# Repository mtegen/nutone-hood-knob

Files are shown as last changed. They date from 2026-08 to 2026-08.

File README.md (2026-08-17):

# NuTone range-hood control knob — 3D-printed replacement

A replacement for the broken control knob on a NuTone kitchen range hood (the "exhaust
ON·OFF·LOW / SOLID STATE" panel). The original is a sixty-ish-year-old moulded knob whose
socket had split.

**Status: printed and working.** ✅ The part as modelled here fits the hood's shaft and drives
the switch. See [What the print confirmed](#what-the-print-confirmed).

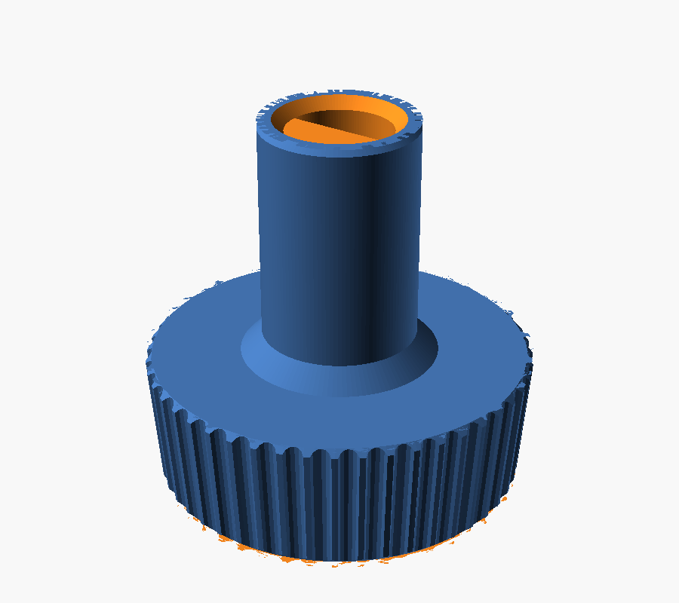
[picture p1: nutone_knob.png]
the knob


## The part

```
        <-------- 27.35 back -------->      the dial you turn, knurled,
         ___________________________        tapering to 25.80 at the front
        |                           |       9.50 tall
        |___________________________|
                |         |                 <- stem 11.00, parallel
                |         |                    17.00 long
                |  Ø7.00  |                    2.00 of wall around the bore
                |  D bore |
                |_________|

                overall 26.50 = 9.50 + 17.00
```

**The overall height is derived, never entered** — it is dial + stem and nothing else, so the
two heights cannot disagree with a third number.

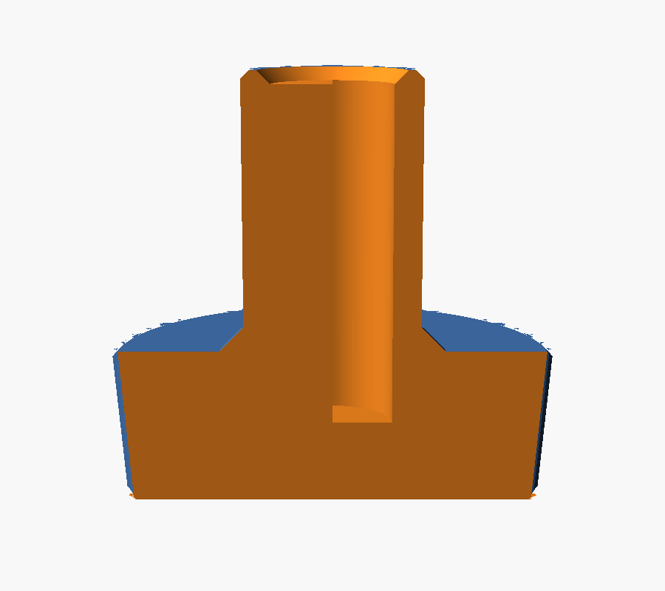
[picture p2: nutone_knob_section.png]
section


## Files

| | |
|---|---|
| `nutone_knob.scad` | the model — every dimension is one variable at the top |
| `nutone_knob.stl` | the knob, ready to print |
| `nutone_knob_gauge.stl` | fit gauge, six stations, ~2 min print |
| `check_stl.py` | is the mesh one solid, closed, and grounded? |
| `measure_stl.py` | is it the right size? measures the STL, not the model's arithmetic |
| `clean_stl.py` | drops zero-area facets from the export |

## Printing

- **Orientation: front face DOWN on the plate, stem pointing up.** The bore then prints as a
  clean vertical blind hole needing no support, and elephant foot lands on the dial's front
  rim where the 0.60 chamfer absorbs it, not on a fit surface. Stem-down would put the splay
  right at the bore mouth — the one place it must not be — and need support under the dial.
- **No supports needed anywhere.** The dial's taper is 2.6° off vertical and the gusset is a
  45° cone; both are self-supporting.
- 0.16 mm layers, **4 walls**, 30–40 % infill.
- ⚠ **Walls, not infill, resist the twist.** Torque tries to shear the stem along the layer
  lines, which is FDM's weak direction — hence four perimeters. The 1.5 mm gusset at the
  stem/dial junction is there for the same reason: that corner is where the original broke.

### Material

PLA prints this fine and is the most dimensionally predictable choice. The reservation is
that this is a **range hood** — PLA softens around 60 °C and creeps under sustained load, and
a knob pressed onto a shaft is under constant load. PETG (~80 °C) or ASA (~100 °C) have real
margin. If the panel on your hood runs warm, use one of those for the keeper.

## Print the gauge first

Two minutes, against a shaft you would otherwise be guessing at.

```bash
openscad -D 'part="gauge"' -o nutone_knob_gauge.stl nutone_knob.scad
```

Six stations: five D sockets stepping the bore, one plain round hole as a control.

- **A D station grips firmly and square** → that is your number. Set `socket_fit` so `bore_d`
  matches it, re-export, print the knob.
- **No D station goes on but the round control does** → the bore is fine and the **flat** is
  wrong. Measure flat face → opposite arc and raise `shaft_flat`.
- **Nothing goes on at all** → `shaft_d` is under. Raise it.

| Station | Modelled bore | Prints about |
|---|---|---|
| `14` | 7.14 | 6.95 — tight |
| `24` | 7.24 | 7.05 |
| `34` | 7.34 | **7.15 — the knob's default** |
| `44` | 7.44 | 7.25 |
| `54` | 7.54 | 7.35 — loose |
| `RND` | 7.34 round, no flat | control |

## The measurements

All taken with calipers on the shaft and the old knob.

| | |
|---|---|
| `shaft_d` 7.00 | across the shaft's round part at its widest, measured on the **shaft** — a cracked socket splays and reads oversize |
| `stem_d` 11.00 | parallel, does not taper |
| `stem_l` 17.00 | how far the stem stands off the back of the dial |
| `grip_d_back` 27.35 | widest, against the panel |
| `grip_d_front` 25.80 | the face you look at |
| `grip_t` 9.50 | the dial's own height |

⚠ **Do not scale these off photographs.** An earlier revision derived the dial from the
photos and got 22.7 against a real 27.35 — 20 % out. Photographs settle the *shape* on this
job; they have no business setting a *size*. Where a caliper reading and a pixel ratio
disagreed here, the pixels were wrong every time.

## Printer compensation

Built on a Bambu A1 mini's **measured** behaviour, not published ranges. Three effects, all
compensated in the model so the STL is correct whoever slices it:

| Effect | Value | Applied as |
|---|---|---|
| Holes print under | `hole_shrink` 0.19 | bore drawn **over**: `7.00 + 0.19 + 0.15 fit = 7.34` |
| Outsides print over | `ext_grow` 0.15 | every outer dia drawn **under**: 25.80 → 25.65 |
| Elephant foot | `foot_chamfer` 0.60 | chamfer on the front face, which sits on the plate |

0.19 is interpolated for Ø7 between measured 0.20 at Ø6 and 0.15 at Ø10; shrinkage scales
with hole-to-nozzle ratio, so the small-hole figure does not carry across.

This is why the STL measures "wrong" in a viewer — 25.65 where you expect 25.80. It is drawn
small on purpose so it comes off the plate at size.

⚠ **If you enable X-Y hole/contour compensation or elephant-foot compensation in your slicer,
zero `hole_shrink`, `ext_grow` and `foot_chamfer` here** — otherwise it is applied twice and
the socket comes out ~0.19 too loose.

## What the print confirmed

The knob printed from `nutone_knob.stl` fits the shaft and drives the switch. That retires the
last open assumption:

- ✅ **`shaft_flat` = 3.50 — the shaft really is a true half-round**, flat through the centre.
  This was an inference from the words "a half circle" and was the single most likely thing
  to be wrong. The part going on proves it.
- ✅ **The bore at 7.34 modelled is right** — the 0.19 hole-shrink and 0.15 clearance together
  land where they should on a 7.00 shaft.
- ✅ **The compensation figures carry to this part**, at least in the material used for this
  print. (Material for the successful print is not recorded here — worth noting if you
  reprint in something else, since PETG and PLA do not shrink identically.)

## Verified dimensions

Measured back off the exported STL with `measure_stl.py`, not taken from the model:

| Feature | Modelled | Prints |
|---|---|---|
| Overall height | 26.50 | — |
| Dial, front | 25.65 | 25.80 |
| Dial, back (widest, z=9.04) | 27.13 | 27.28 |
| Stem (z 9.50 → 26.00) | 10.85 | 11.00 |
| Bore | 7.34, flat on centre | ~7.15 |
| Wall around bore | 1.76 | 1.93 |
| Front face | 5.00 solid | socket 21.50 deep |

## If it does not fit

Every fit is one variable at the top of the `.scad`. Change one, re-export, re-verify.

| Symptom | Change |
|---|---|
| Socket will not start on the shaft | raise `socket_fit` (0.15 → 0.25) |
| Socket goes on but the knob spins | lower `socket_fit`; if it still spins, `shaft_flat` is too big — the flat is not driving |
| No bore goes on, round control does | lower `shaft_flat` — the flat is cut deeper than half |
| Knob will not seat flush to the panel | raise socket depth: lower `front_wall` (5.00 → 3.00) |
| Knob stands too proud / too deep | change `grip_t` or `stem_l`; overall follows automatically |
| Stem splits while pressing on | raise `socket_fit`, print PETG, raise `fillet` |
| Knurl feels smooth | raise `flute_depth` (0.45 → 0.60) or lower `flutes` (48 → 36) |

## Verifying an export

```bash
openscad -D 'part="knob"' -o nutone_knob.stl nutone_knob.scad \
  && python3 clean_stl.py nutone_knob.stl \
  && ./check_stl.py nutone_knob.stl \
  && ./measure_stl.py nutone_knob.stl
```

`clean_stl.py` is needed because where a chamfer cone meets a flank the two surfaces are
tangent along a ring, and CGAL tessellates that into zero-area slivers (48 on the current
version). They enclose no volume but leave edges pairing with nothing, so `check_stl.py`
counts them as open. Dropping them took the count to **zero**, which is the proof there was
never a hole — a real hole would have survived the drop. **Always re-run `check_stl.py` after
cleaning**; the cleaner is not trusted on its own say-so.

## Not modelled

The white printed insert in the original's front face. `insert_recess = false` ships a flat
front — the insert's diameter was never measured, and printing front-face-down turns a recess
into a bridged ceiling. Options: reuse the original insert glued to the flat front, or set
`insert_recess = true` with a real `insert_d` and accept the bridge.

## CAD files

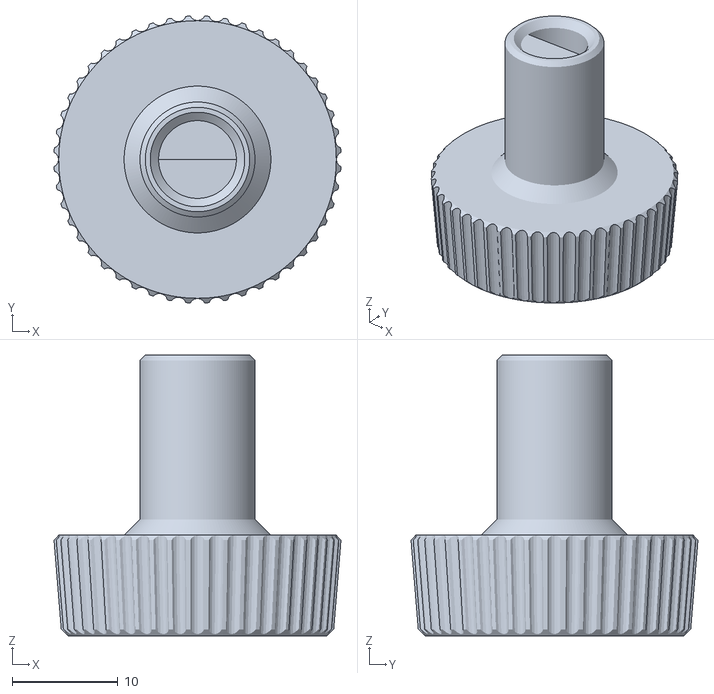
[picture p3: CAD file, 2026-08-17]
nutone_knob.stl
27.1 x 27.1 x 26.5

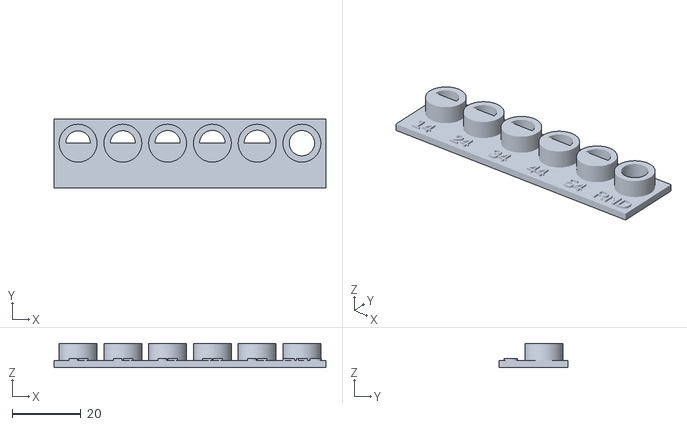
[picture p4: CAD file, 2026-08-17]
nutone_knob_gauge.stl
79.0 x 20.0 x 7.00

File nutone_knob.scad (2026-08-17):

// NuTone range-hood control knob — replacement
//
// Standalone. Nothing here is shared with any other project.
//
// ⚠ THE SHAPE IS STEPPED. A NARROW STEM carries the D socket; behind it a MUCH WIDER KNURLED
// GRIP is the part a person touches. An early version modelled the whole thing as one 10.8
// tube. That was wrong and the owner caught it.
//
// ⚠ SIZES ARE MEASURED, NOT SCALED OFF PHOTOGRAPHS. An earlier version derived the grip from
// the photos and got 22.7 against a real 27.35 — 20% out. Photographs settle the SHAPE here;
// they have no business setting a SIZE.
//
// ⚠ THE OVERALL HEIGHT IS DERIVED, NOT ENTERED. It is grip_t + stem_l and nothing else, so
// the two heights can never disagree with a third number. Asking for an overall reading when
// both pieces were already given was my mistake, not a missing measurement.
//
//        <-------- grip_d 27.35 back -------->    the part you touch, knurled,
//         ___________________________________     tapering to 25.80 at the front
//        |                                   |    grip_t 9.50
//        |___________________________________|
//                    |         |                  <- stem_d 11.00, parallel
//                    |         |                     stem_l 17.00
//                    |  O7.00  |                     2.00 of wall around the bore
//                    |  D bore |
//                    |         |
//                    |_________|
//
//                    overall 26.50 = 9.50 + 17.00
//
// Exports:
//   openscad -D 'part="knob"'  -o nutone_knob.stl       nutone_knob.scad
//   openscad -D 'part="gauge"' -o nutone_knob_gauge.stl nutone_knob.scad

part = "knob";              // "knob" | "gauge" | "section"

/* ---- MEASURED by the owner, with calipers ------------------------------------------ */
shaft_d      = 7.00;       // MEASURED on the hood's shaft itself, across the round part at
                           // its widest. Measured on the SHAFT, not the broken socket — a
                           // cracked socket splays open and reads oversize.
stem_d       = 11.00;      // MEASURED. Parallel — it does NOT taper.
stem_l       = 17.00;      // MEASURED, how far the stem stands off the back of the dial
grip_d_back  = 27.35;      // MEASURED, at the back — the widest end, against the panel
grip_d_front = 25.80;      // MEASURED, at the front — the face you look at
grip_t       =  9.50;      // MEASURED, the dial's own height

/* ---- STILL NOT MEASURED — each is one variable ------------------------------------- */
shaft_flat   = 3.50;       // ⚠ ASSUMED a TRUE half-round: the flat through the shaft's
                           // centre, which is what "a half circle" encodes. If the flat is
                           // cut shallower this number is bigger and the socket will not go
                           // on. Measure flat face -> opposite arc. The gauge's round
                           // control station exists to catch exactly this.
front_wall   = 5.00;       // ⚠ CHOSEN, not measured. Sets the socket depth, and the error is
                           // ONE-SIDED: a socket deeper than the shaft costs nothing — the
                           // shaft just does not reach the bottom and the D drives the knob
                           // the same — while a socket shallower than the shaft stops the
                           // knob seating flush to the panel. So this errs deep on purpose.

/* ---- WHAT THE PRINTER DOES TO THESE NUMBERS -----------------------------------------
   Bambu A1 mini, 0.4 nozzle. Not published ranges — what this printer was measured doing:
     HOLES SHRINK   0.20 at O6, 0.15 at O10. Scales with hole-to-nozzle ratio, so O7 is
                    interpolated rather than taking the small-hole figure.
     OUTSIDES GROW  0.15.
     ELEPHANT FOOT  first layers splay; the front chamfer is sized for it, not decorative.
   ⚠ If you switch these on in Bambu Studio instead, zero them here or they apply twice. */
hole_shrink  = 0.19;
ext_grow     = 0.15;
foot_chamfer = 0.60;
edge_chamfer = 0.50;

socket_fit   = 0.15;       // diametral clearance, socket over shaft — a light press. The
                           // knob is held on by friction; the original has no set screw.

/* ---- APPEARANCE ---------------------------------------------------------------------- */
flutes       = 48;         // knurl count on the GRIP. 48 around 27.35 is a 1.79 mm pitch,
                           // which a 0.4 nozzle can actually render. Finer just blobs.
flute_depth  = 0.45;
fillet       = 1.50;       // gusset where the stem meets the grip. Not cosmetic — this is
                           // the junction that carries all the torque, and the original
                           // broke at the stem.
insert_recess= false;      // the original's white printed disc; see NUTONE-KNOB.md
insert_d     = 21.00;
insert_deep  = 0.80;

$fn = 128;

/* ==== DERIVED ========================================================================= */
total_h   = grip_t + stem_l;                 // 26.50 — the owner's two heights, added
socket_depth = total_h - front_wall;         // 21.50 — through the stem, into the grip

bore_d    = shaft_d + hole_shrink + socket_fit;
bore_r    = bore_d / 2;
bore_flat = shaft_flat + (hole_shrink + socket_fit) / 2;
flat_y    = bore_r - bore_flat;              // 0 when it is a true half-round

gd_front  = grip_d_front - ext_grow;
gd_back   = grip_d_back  - ext_grow;
sd        = stem_d       - ext_grow;

/* ==== PARTS =========================================================================== */

// The D socket, as a solid to subtract. Origin at its mouth, growing +z.
module d_socket(depth) {
    intersection() {
        cylinder(d = bore_d, h = depth);
        translate([-bore_d, flat_y, 0]) cube([2 * bore_d, 2 * bore_d, depth]);
    }
}

// Removes everything outside a 45-degree cone, giving a chamfer in a thin z band.
// grow=true chamfers a bottom edge, false chamfers a top edge.
module chamfer_ring(z0, d, ch, grow = true) {
    translate([0, 0, z0]) difference() {
        cylinder(d = d + 10, h = ch);
        if (grow) cylinder(d1 = d - 2 * ch, d2 = d + 0.01, h = ch);
        else      cylinder(d1 = d + 0.01,   d2 = d - 2 * ch, h = ch);
    }
}

// The knurled grip, tapering front to back. Knurl on the grip only — the stem is smooth,
// as on the original.
// ⚠ The flute cutters get their OWN low segment count. Left on $fn=128 a 1.4 mm circle is
// tessellated far finer than the printer can resolve, and where those arcs cross the body's
// arc they produce zero-area sliver triangles.
module grip() {
    linear_extrude(height = grip_t, scale = gd_back / gd_front, convexity = 10)
        difference() {
            circle(d = gd_front);
            for (i = [0 : flutes - 1])
                rotate([0, 0, i * 360 / flutes])
                    translate([gd_front / 2 + 0.70 - flute_depth, 0])
                        circle(d = 1.40, $fn = 16);
        }
}

module knob() {
    difference() {
        union() {
            grip();
            translate([0, 0, grip_t]) cylinder(d = sd, h = stem_l);          // the stem
            translate([0, 0, grip_t])                                        // the gusset
                cylinder(d1 = sd + 2 * fillet, d2 = sd, h = fillet);
        }

        // The socket, opening at the stem tip and reaching down into the grip.
        translate([0, 0, total_h - socket_depth]) d_socket(socket_depth + 0.1);

        // Lead-in at the mouth so the knob starts onto the shaft square. 45 degrees, which
        // prints as a self-supporting overhang.
        translate([0, 0, total_h - 0.80])
            cylinder(d1 = bore_d, d2 = bore_d + 1.60, h = 0.81);

        // Front face: elephant-foot relief. This face goes on the plate.
        chamfer_ring(0, gd_front, foot_chamfer, true);
        // Back of the grip, and the stem tip.
        chamfer_ring(grip_t - edge_chamfer, gd_back, edge_chamfer, false);
        chamfer_ring(total_h - edge_chamfer, sd, edge_chamfer, false);

        if (insert_recess)
            translate([0, 0, -0.01]) cylinder(d = insert_d + hole_shrink, h = insert_deep);
    }
}

/* ==== THE FIT GAUGE ==================================================================
   Six stations: five D sockets stepping the bore, plus one plain ROUND hole as a control.
     - A D station grips firmly and square -> that is your number.
     - None of the D stations go on but the round one does -> the bore is fine and the FLAT
       is wrong. Measure flat-to-far-arc and raise shaft_flat.
   Labels are the modelled bore in hundredths, dropping the leading 7. "34" is the default. */
gauge_bores  = [7.14, 7.24, 7.34, 7.44, 7.54];
gauge_labels = ["14", "24", "34", "44", "54"];
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
